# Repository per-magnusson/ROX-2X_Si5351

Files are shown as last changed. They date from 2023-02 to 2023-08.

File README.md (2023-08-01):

# ROX-2X_Si5351
Si5351 controller for a 2 m ARDF receiver, based on a Raspberry Pi Pico board

This code controls an Si5351 chip to work as the local oscillator in a direction
finding receiver for the 2 m band (144 MHz). The user interface is a 2x16 alphanumeric
LCD, a rotary encoder and four membrane buttons. It was designed to replace the 
VCO of the ROX-2X ARDF receiver, see http://open-circuit.co.uk/wp/receivers/rox-2x/

The PDF shows the connections around the Pi Pico as well as how the ROX-2X board was 
modified.

The Si5351 library from Adafruit was used, but significantly modified/extended to 
support the needs of this project.

Potentially interesting code includes:

* Extended Adafruit Si5351 library
* Interrupt driven rotary encoder
* An algorithm based on Farey fractions to approximate doubles with fractions

The normal view during an ARDF competition is that the top row of the display shows the battery status and 
a bar with the signal strength (RSSI). The length of this bar is dependent on the 
analog gain setting but could potentially be used to compare the signal along different 
bearings. Normally one would however just listen to the audio RSSI while sweeping the 
antenna in different directions.

The second row shows the tuned frequency and which of the preprogrammed frequencies is
currently selected. 

If neither the encoder, nor any of the four membrane keys have been used for the last 
10 seconds, they all become locked, except for key 1 which unlocks them. When they are 
unlocked, they have the following functions:

* 1, edit a more significant digit in the frequency.
* 2, edit a less significant digit in the frequency.
* 3, step to the next stored frequency.
* 4, hold for a second to enter the "menu". "M" is shown in the lower right corner during this waiting period.
* Encoder, increment/decrement the currently active digit of the frequency.

When in the "menu", the first view allows editing of the stored frequencies. Key 1 changes which 
digit is edited. Key 2 jumps to the next frequency (up to 9 stored frequencies are supported). 
Key 3 stores the frequencies up to and including the currently selected frequency. 
Key 4 aborts this step and goes to the next menu screen without modifying the stored frequencies.

The second menu screen just shows the battery voltage. Pressing 4 moves on to the next screen.

The third menu screen can activate a function to characterize the pass band response 
(including the image reponse) of the receiver. A USB cable where a serial terminal looks at the printed 
output from the reciever shall be used to collect the resulting frequency/amplitude value pairs
which can then be plotted in e.g. Excel. An internal signal generator is used to create the 
test RF signal. Ideally, no antenna should be connected during this test. The result depends on the
gain setting. Press 1 to run this test or 4 to skip it.

The fourth menu item sweeps the tuning across the band and reports the RSSI at many frequencies 
as printouts on the USB serial port. This test could be used to look for internal disturbances from
the receiver itself, particularly if no antenna is connected during the test. The result depends on the
gain setting. Press 1 to run this test or 4 to skip it.

After the fourth menu screen, we are back to the main view used during a competition. So, to quickly go through the menus
if one accidentally enters it, key 4 can be pressed a couple of times to get back to the standard view.

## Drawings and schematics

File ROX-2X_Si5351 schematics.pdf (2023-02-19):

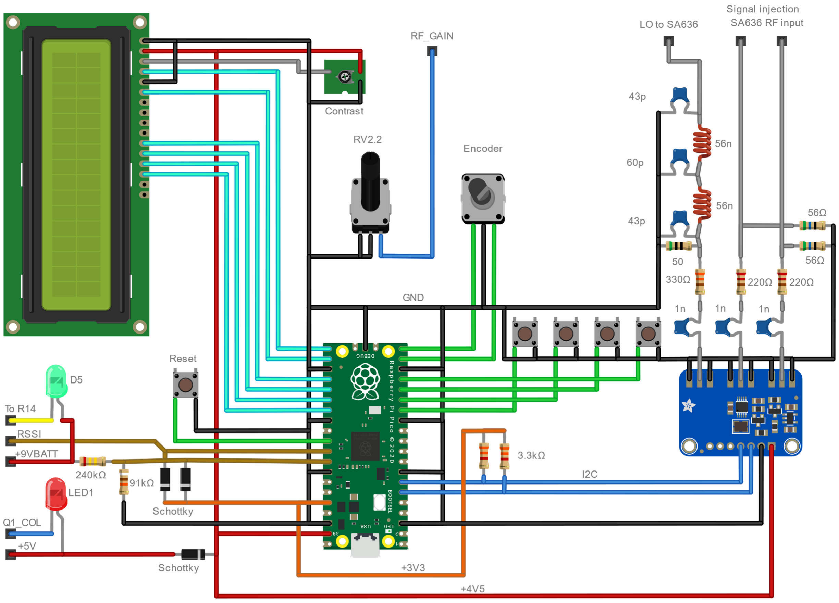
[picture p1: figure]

”Breadboard” connections for the Pi Pico, LCD, Si5351 board etc.

# Modified ROX-2X ARDF Receiver by G3ZOI

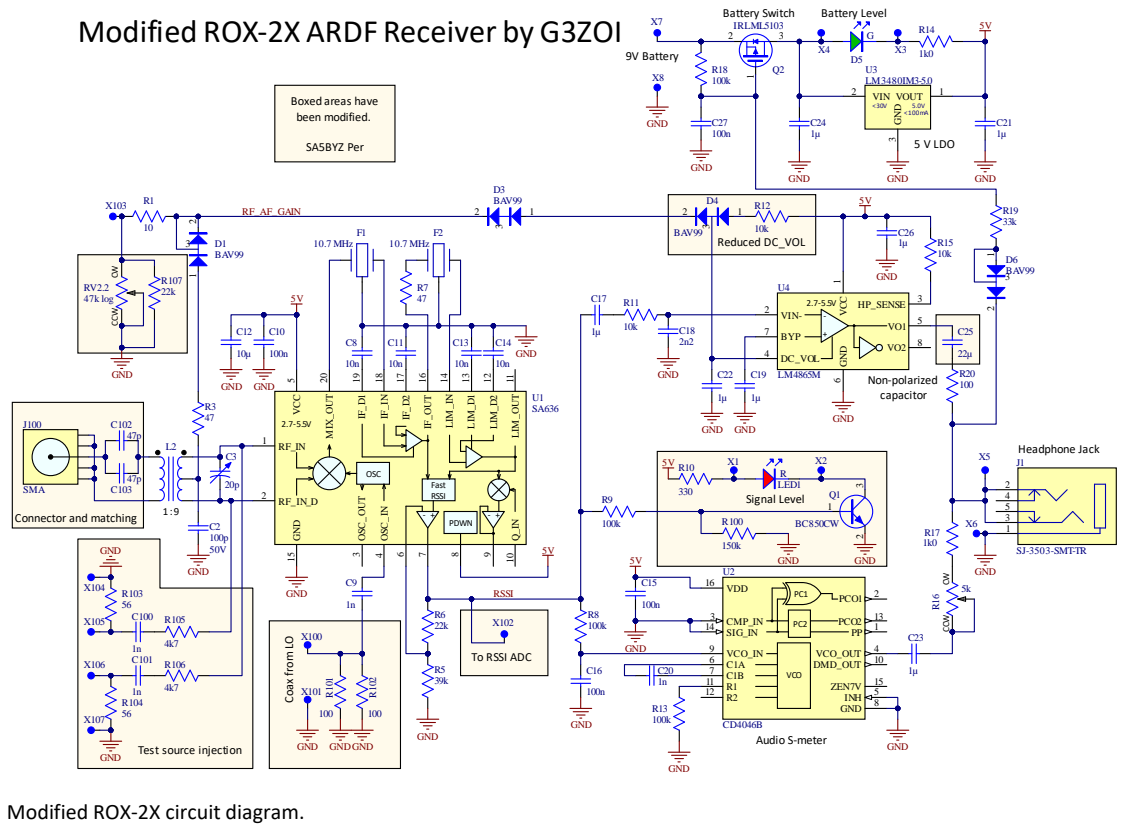
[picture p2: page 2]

Modified ROX-2X circuit diagram.

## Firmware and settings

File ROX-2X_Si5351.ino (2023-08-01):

// 2 m ARDF receiver local oscillator controller for ROX-2X
// based on an Raspberry Pi Pico board.
// Set the CPU clock frequency to 50 MHz in the Arduino IDE (Tools->CPU speed)
// to not have it near the LO and to save current.
// 2023-01-08 Per Magnusson
// This code is under the MIT license.

#include <LiquidCrystal.h>
#include <Bounce2.h>
#include <pico/stdlib.h>
#include "Encoder2.h"
#include "Adafruit_SI5351.h"
#include "Wire.h"
#include "rox2x.h"
#include "eeprom_2m.h"

static const int BUTTON1_Pin = 10;
static const int BUTTON2_Pin = 11;
static const int BUTTON3_Pin = 12;
static const int BUTTON4_Pin = 13;
static const int ENCODER_I_Pin = 14;
static const int ENCODER_Q_Pin = 15;
static const int LCD_RS_Pin = 16;
static const int LCD_EN_Pin = 17;
static const int LCD_D4_Pin = 18;
static const int LCD_D5_Pin = 19;
static const int LCD_D6_Pin = 20;
static const int LCD_D7_Pin = 21;
static const int RSSI_Pin = A0;
static const int DIV_9V_Pin = A1;

static const int LCD_WIDTH = 16;
static const int LCD_HEIGHT = 2;

static const int MENU_DLY_MS = 1000;  // Number of millisseconds to hold button to enter menu
static const int EDIT_DLY_MS = 10000; // Number of millisseconds until frequency edit is locked after last action

static const int MIN_FREQ_EDIT = 1000; // Hz, lowest increment when editing frequencies (the passband is about 50 kHz wide)
static const int MAX_FREQ_EDIT = 100000; // Hz, highest increment when editing frequencies
static const int MAX_TUNING_ERROR = 0; // Hz, maxmimum allowed deviation from ideal tuning frequency.
// There was speculation that higher values might give lower jitter since that allows a lower
// denominator, but actual measurements of spectra does not give a clear indication that that
// would be better.



// Voltage divider of 240k and 91k, 3.3 V ADC reference, 10 bits resolution and a fudge factor
static const float BATT_SCALE = 1.03*3.3*(240 + 91)/91/1024; 
static const float BATT_HIGH = 8.8; // Voltage regarded as full battery
static const float BATT_LOW = 6.5;  // Voltage regarded as empty battery
static const float BATT_LEVELS = 7; // Number of levels of battery indicator, one is below low and one is above high
static const float BATT_STEP = (BATT_HIGH - BATT_LOW)/(BATT_LEVELS - 2);


LiquidCrystal lcd(LCD_RS_Pin, LCD_EN_Pin, LCD_D4_Pin, LCD_D5_Pin, LCD_D6_Pin, LCD_D7_Pin);

Adafruit_SI5351 si5351 = Adafruit_SI5351();

Bounce button1 = Bounce();
Bounce button2 = Bounce();
Bounce button3 = Bounce();
Bounce button4 = Bounce();

uint32_t freq;  // Hz
uint32_t frequencies[10]; // Hz, read from EEPROM at power up, can be modified during use. 1-based, so only index 1-9 are used.
uint32_t max_frequency_idx = 1; // Highest used pre-programmed (EEPROM) frequency index
uint32_t current_freq_idx = 1;

static const int PLL_DELAY = 30; // Number of ms to wait after retuning a PLL

// Frequency sweeping parameters
static const uint SWEEP_FREQ_MIN = 144000000; // Hz
static const uint SWEEP_FREQ_MAX = 146000000;
static const uint SWEEP_FREQ_STEP_COARSE = 10000;
static const uint SWEEP_FREQ_STEP_FINE = 2000;
static const uint SWEEP_RSSI_AVG = 1000; // Number of RSSI measurements to average during sweeping


static const uint32_t IF_FREQ = 10700000; // Hz
int i2c_found;

void isr_a(void);
void isr_b(void);
void tune_pll(uint32_t pll_freq, uint32_t tolerance, si5351PLL_t pll);
void tune_freq(uint32_t freq);
void step_frequency();
float read_rssi(int n = 1);
int update_rssi();
float update_batt(uint32_t period_ms = 200);
void lcd_print_freq(uint32_t freq);
char *format_MHz(uint64_t freq);
void enable_test_source(uint32_t freq);
void disable_test_source();
void show_sweep_freq(uint32_t sweep_freq);


Encoder2 rot_enc(ENCODER_I_Pin, ENCODER_Q_Pin, isr_a, isr_b);

// Special LCD character codes
static const byte CHAR_BLOCK = 0; // Full block, used for RSSI
static const byte CHAR_RSSI = 1;  // Modifed block, used for top of RSSI
static const byte CHAR_BATT = 2;  // Modified battery level symbol
static const byte CHAR_RIGHT_ARROW = 3;  // Arrow pointing right
static const byte CHAR_ENTER = 4; // "Enter" sign

// Modifiable glyph for RSSI indication, starts out as a full block
byte glyph[8] = {
  0b11111,
  0b11111,
  0b11111,
  0b11111,
  0b11111,
  0b11111,
  0b11111,
  0b11111
};

// Glyphs for battery indication
byte batt_glyphs[7][8] = {
  {0b01110, 0b10001, 0b10001, 0b10001, 0b10001, 0b10001, 0b10001, 0b11111},
  {0b01110, 0b10001, 0b10001, 0b10001, 0b10001, 0b10001, 0b11111, 0b11111},
  {0b01110, 0b10001, 0b10001, 0b10001, 0b10001, 0b11111, 0b11111, 0b11111},
  {0b01110, 0b10001, 0b10001, 0b10001, 0b11111, 0b11111, 0b11111, 0b11111},
  {0b01110, 0b10001, 0b10001, 0b11111, 0b11111, 0b11111, 0b11111, 0b11111},
  {0b01110, 0b10001, 0b11111, 0b11111, 0b11111, 0b11111, 0b11111, 0b11111},
  {0b01110, 0b11111, 0b11111, 0b11111, 0b11111, 0b11111, 0b11111, 0b11111}
};

// Right arrow for use in menu
byte right_arrow_glyph[8] = {
  0b00000,
  0b00100,
  0b00010,
  0b11111,
  0b00010,
  0b00100,
  0b00000,
  0b00000
};

// "Enter" arrow for use in menu
byte enter_glyph[8] = {
  0b00000,
  0b00001,
  0b00001,
  0b01001,
  0b11111,
  0b01000,
  0b00000
};


void setup() {
  Serial.begin(115200);

  rp2040.enableDoubleResetBootloader();
  eeprom_init();
  max_frequency_idx = recall_frequencies(frequencies);
  current_freq_idx = 1;
  freq = frequencies[current_freq_idx];

  rot_enc.begin();
  button1.attach(BUTTON1_Pin, INPUT_PULLUP);
  button1.interval(10);
  button2.attach(BUTTON2_Pin, INPUT_PULLUP);
  button2.interval(10);
  button3.attach(BUTTON3_Pin, INPUT_PULLUP);
  button3.interval(10);
  button4.attach(BUTTON4_Pin, INPUT_PULLUP);
  button4.interval(10);

  si5351.begin();
  si5351.powerDownOutput(0, false);
  si5351.enableOutput(0, true);
  si5351.outputDrive(0, SI5351_DRIVE_2MA);
  si5351.outputDrive(1, SI5351_DRIVE_2MA);
  si5351.outputDrive(2, SI5351_DRIVE_2MA);
  si5351.invertOutput(2, true);
  si5351.enableOutput(1, false);
  si5351.enableOutput(2, false);
  si5351.setupMultisynthInt(0, SI5351_PLL_A, SI5351_MULTISYNTH_DIV_6);
  si5351.setupMultisynthInt(1, SI5351_PLL_B, SI5351_MULTISYNTH_DIV_6);
  si5351.setupMultisynthInt(2, SI5351_PLL_B, SI5351_MULTISYNTH_DIV_6);
  si5351.powerDownOutput(1, true);
  si5351.powerDownOutput(2, true);

  delay(PLL_DELAY);
  tune_freq(freq);
  si5351.resetPLL(SI5351_PLL_A);
  tune_pll(6*freq, 6*MAX_TUNING_ERROR, SI5351_PLL_B);
  si5351.resetPLL(SI5351_PLL_B);
  delay(PLL_DELAY);

  // set up the LCD's number of columns and rows:
  lcd.begin(LCD_WIDTH, LCD_HEIGHT);
  // Define custom characters
  lcd.createChar(CHAR_BLOCK, glyph);
  lcd.createChar(CHAR_BATT, batt_glyphs[6]);
  lcd.createChar(CHAR_RIGHT_ARROW, right_arrow_glyph);
  lcd.createChar(CHAR_ENTER, enter_glyph);

  // The following does not seem to work. Maybe better low-power functionality will be
  // added in the future. For now, the best thing to do seems to be to set the 
  // clock frequency to 50 MHz in the IDE.

  // Set clock frequency to 15.43 MHz to save power
  // set_sys_clock_khz(15429, false); 
  // Reduce core voltage
  // vreg_set_voltage(VREG_VOLTAGE_1_00); // 0.85V did not work, 0.95V seems pretty stable
}



// States of the "UI" state machine
typedef enum {
  S_FREQ_INIT, // Setup LO PLL
  S_FREQ_EDIT, // Rotating the dial adjusts the frequency
  S_BUTTON_LOCK, // Rotating the dial does not affect the frequency, button 1 needs to be pressed to unlock
  S_FREQ_MENU_DLY, // Waiting for button 4 to be pressed long enough to enter the menu
  S_MENU_FREQ1, // Init first menu (frequency edit)
  S_MENU_FREQ2, // Edit frequencies
  S_MENU_SHOW_SAVED, // Show "saved" message
  S_MENU_SHOW_CANCEL, // Show "cancelled" message
  S_MENU_BATT1, // Show battery voltage 1
  S_MENU_BATT2, // Show battery voltage 2
  S_MENU_SWEEP_RESP0, // Sweep passband reponse?
  S_MENU_SWEEP_RESP1, // Sweep passband!
  S_MENU_SWEEP_RESP2, // Sweep  
  S_MENU_SWEEP_RESP3, // Sweep  
  S_MENU_SWEEP_RESP4, // Sweep  
  S_MENU_SWEEP_RESP5, // Sweep  
  S_MENU_SWEEP_RESP6, // Sweep  
  S_MENU_SWEEP_RESP7, // Sweep  
  S_MENU_SWEEP_RESP_DONE1, // After sweep passband 
  S_MENU_SWEEP_RESP_DONE2, // After sweep  
  S_MENU_SWEEP_RESP_DONE3, // After sweep  
  S_MENU_SWEEP_BAND0, // Sweep entire band to e.g. listen for internal noise?
  S_MENU_SWEEP_BAND1, // Sweep
  S_MENU_SWEEP_BAND2, // Sweep
  S_MENU_SWEEP_BAND3, // Sweep
  S_MENU_SWEEP_BAND_DONE1, // After band sweep  
  S_MENU_SWEEP_BAND_DONE2 // After band sweep  
} uiState_t;


void loop()
{
  static uint64_t f_increment = 10000;  // Current rotary encoder frequency increment
  static int force_freq_update = 1;
  static uiState_t state = S_FREQ_INIT;
  static uint32_t last_button_time;
  static int edit_freq_idx;
  static uint32_t sweep_freq;
  int rot_temp;
  int cursor_has_moved = 0;  
  
  if(state < S_MENU_FREQ1) {
    // Only update RSSI etc if we are not in the menu
    cursor_has_moved = update_rssi();
    update_batt();
  }

  // GUI state machine
  if(state == S_FREQ_INIT) { // ##################################    S_FREQ_INIT
    si5351.powerDownOutput(0, false);
    si5351.outputDrive(0, SI5351_DRIVE_2MA);
    si5351.enableOutput(0, true);
    si5351.setupMultisynthInt(0, SI5351_PLL_A, SI5351_MULTISYNTH_DIV_6);
    tune_freq(freq);
    si5351.resetPLL(SI5351_PLL_A);
    delay(PLL_DELAY);
    state = S_FREQ_EDIT;

  } else if(state == S_FREQ_EDIT) { // ##################################    S_FREQ_EDIT
    button1.update();
    if(button1.fell()) {
      f_increment *= 10;
      last_button_time = millis();
      cursor_has_moved = 1;
    }
    button2.update();
    if(button2.fell()) {
      f_increment /= 10;
      last_button_time = millis();
      cursor_has_moved = 1;
    }
    if(f_increment > MAX_FREQ_EDIT) {
      f_increment = MIN_FREQ_EDIT;
    }
    if(f_increment < MIN_FREQ_EDIT) {
      f_increment = MAX_FREQ_EDIT;
    }
    button3.update();
    if(button3.fell()) {
      // Step to the next stored frequency.
      last_button_time = millis();
      step_frequency();
      force_freq_update = 1;  
    }
    button4.update();
    if(button4.fell()) {
      // Button 4 was pressed, we might be entering the menu
      last_button_time = millis();
      lcd.setCursor(14, 1);
      lcd.print(" M");
      state = S_FREQ_MENU_DLY;
    }
    rot_temp = rot_enc.read();
    if (rot_temp != 0 || force_freq_update) {
      force_freq_update = 0;
      last_button_time = millis();
      freq += rot_temp*f_increment;
      frequencies[current_freq_idx] = freq;
      rot_enc.write(0);
      tune_freq(freq);
      lcd.setCursor(0, 1);
      lcd_print_freq(freq);
      lcd.setCursor(15, 1);
      lcd.print(current_freq_idx); // Index of current frequency
      cursor_has_moved = 1;
      Serial.print(format_MHz(freq));
      Serial.print(" #");
      Serial.println(current_freq_idx);
    }
    if(cursor_has_moved) {
      // Enable and position the cursor to mark which digit of the frequency we can adjust.
      if(f_increment >= 100000) {
        lcd.setCursor(4, 1);
      } else if(f_increment >= 10000) {
        lcd.setCursor(5, 1);
      } else if(f_increment >= 1000) {
        lcd.setCursor(6, 1);
      } else {
        lcd.setCursor(8, 1);
      }
      lcd.cursor();
    }

    if(millis() > last_button_time + EDIT_DLY_MS) {
      // Button time out, lock the frequency
      state = S_BUTTON_LOCK;
      lcd.noCursor();
    }
 
  } else if(state == S_BUTTON_LOCK) { // ##################################    S_BUTTON_LOCK
    // The encoder is ignored in this state, need to press button 1 to unlock
    rot_enc.write(0); // Do not collect encoder clicks in this state
    button1.update();
    if(button1.fell()) {
      last_button_time = millis();
      lcd.clear();
      force_freq_update = 1;
      state = S_FREQ_EDIT;
    }

  } else if(state == S_FREQ_MENU_DLY) { // ##################################    S_FREQ_MENU_DLY
    // Button 4 has been pressed, we are waiting to see 
    // if it is held down long enough to enter the menu.
    button4.update();
    if(button4.read() == HIGH) {
      // The button was released early, go back to edit state
      last_button_time = millis();
      lcd.setCursor(14, 1);
      lcd.print("  "); // Overwrite menu countdown.
      state = S_FREQ_EDIT;
    } else {
      // Still holding the button
      if(millis() > last_button_time + MENU_DLY_MS) {
        // The button has been held long enough to enter the menu.
        f_increment = 100000;
        state = S_MENU_FREQ1;
      }
    }

  } else if(state == S_MENU_FREQ1) { // ##################################    S_MENU_FREQ1
    // Show the first menu page
    lcd.clear();
    lcd.setCursor(0, 1);
    // Soft buttons:
    // 1: Right (change digit)
    // 2: Next frequency
    // 3: Store this and previous frequencies (but not those with higher indices)
    // 4: Cancel the frequency edit
    lcd.print("1:- 2:+ 3:v  4:X"); 
    lcd.setCursor(2, 1);
    lcd.write(CHAR_RIGHT_ARROW); // Replace '-' with right arrow
    lcd.setCursor(10, 1);
    lcd.write(CHAR_ENTER); // Replace 'v' with enter arrow
    edit_freq_idx = 1;
    force_freq_update = 1;
    state = S_MENU_FREQ2;

  } else if(state == S_MENU_FREQ2) { // ##################################    S_MENU_FREQ2
    // Edit stored frequencies
    button1.update();
    if(button1.fell()) {
      // Change which digit we are editing
      f_increment /= 10;
      if(f_increment < MIN_FREQ_EDIT) {
        f_increment = MAX_FREQ_EDIT;
      }
      cursor_has_moved = 1;
    }
    button2.update();
    if(button2.fell()) {
      // Go to next frequency
      edit_freq_idx++;
      force_freq_update = 1;
      if(edit_freq_idx > 9) {
        edit_freq_idx = 1;
      }
      if(frequencies[edit_freq_idx] < MIN_TUNE_FREQ) {
        frequencies[edit_freq_idx] = DEFAULT_TUNE_FREQ;
      }
      if(frequencies[edit_freq_idx] > MAX_TUNE_FREQ) {
        frequencies[edit_freq_idx] = DEFAULT_TUNE_FREQ;
      }      
    }
    button3.update();
    if(button3.fell()) {
      // Store the frequencies up to and including the current one
      if(edit_freq_idx < 9) {
        frequencies[edit_freq_idx+1] = 0; // Make next frequency invalid to signal the number of valid frequencies
      }
      store_frequencies(frequencies);
      max_frequency_idx = edit_freq_idx;
      freq = frequencies[1];
      current_freq_idx = 1;
      state = S_MENU_SHOW_SAVED;
    }
    button4.update();
    if(button4.fell()) {
      // Cancel the storing of frequencies
      state = S_MENU_SHOW_CANCEL;
    }
    rot_temp = rot_enc.read();
    if (rot_temp != 0 || force_freq_update) {
      force_freq_update = 0;
      frequencies[edit_freq_idx] += rot_temp*f_increment;
      if(frequencies[edit_freq_idx] < MIN_TUNE_FREQ) {
        frequencies[edit_freq_idx] = MIN_TUNE_FREQ;
      }
      if(frequencies[edit_freq_idx] > MAX_TUNE_FREQ) {
        frequencies[edit_freq_idx] = MAX_TUNE_FREQ;
      }
      rot_enc.write(0);
      lcd.setCursor(0, 0);
      lcd_print_freq(frequencies[edit_freq_idx]);
      lcd.setCursor(15, 0);
      lcd.print(edit_freq_idx); // Index of current frequency
      cursor_has_moved = 1;
      Serial.print(format_MHz(frequencies[edit_freq_idx]));
      Serial.print(" #");
      Serial.println(edit_freq_idx);
    }
    if(cursor_has_moved) {
      // Enable and position the cursor to mark which digit of the frequency we can adjust.
      if(f_increment >= 100000) {
        lcd.setCursor(4, 0);
      } else if(f_increment >= 10000) {
        lcd.setCursor(5, 0);
      } else if(f_increment >= 1000) {
        lcd.setCursor(6, 0);
      } else {
        lcd.setCursor(8, 0);
      }
      lcd.cursor();
    }

  } else if(state == S_MENU_SHOW_SAVED) { // ##################################    S_MENU_SHOW_SAVED
    // Show saved message
    lcd.clear();
    lcd.noCursor();
    lcd.setCursor(0, 0);
    lcd.print(edit_freq_idx);
    lcd.print(" frequencies");
    lcd.setCursor(0, 1);
    lcd.print("saved");
    delay(3000);
    state = S_MENU_BATT1;

  } else if(state == S_MENU_SHOW_CANCEL) { // ##################################    S_MENU_SHOW_CANCEL
    // Show cancelled message
    lcd.clear();
    lcd.noCursor();
    lcd.print("Save cancelled");
    delay(500);
    state = S_MENU_BATT1;

  } else if(state == S_MENU_BATT1) { // ##################################    S_MENU_BATT1
    // Show battery voltage, step 1
    float batt;
    lcd.clear();
    lcd.setCursor(0, 0);
    lcd.print("Battery: ");
    batt = BATT_SCALE * analogRead(DIV_9V_Pin);
    lcd.print(batt);
    lcd.print(" V ");
    lcd.setCursor(0, 1);
    lcd.write(byte(CHAR_BATT));
    lcd.print("         4:Next");
    state = S_MENU_BATT2;

  } else if(state == S_MENU_BATT2) {
    // Show battery voltage, step 2
    float batt;
    batt = update_batt(200);
    if(batt > 0) {
      lcd.setCursor(9, 0);
      lcd.print(batt);
    }
    button4.update();
    if(button4.fell()) {
      // Next
      force_freq_update = 1;
      lcd.clear();
      lcd.setCursor(0, 0);
      lcd.print("Sweep response?");
      lcd.setCursor(0, 1);
      lcd.print("1:Sweep   4:Skip");
      enable_test_source(freq); // Turn on the test frequency to facilitate volume adjustment
      state = S_MENU_SWEEP_RESP0;
    }

  } else if(state == S_MENU_SWEEP_RESP0) { // ##################################    S_MENU_SWEEP_RESP0
    // Do a frequency sweep?
    button1.update();
    if(button1.fell()) {
      state = S_MENU_SWEEP_RESP1;
    }
    button4.update();
    if(button4.fell()) {
      disable_test_source();
      state = S_MENU_SWEEP_BAND0;
    }

  } else if(state == S_MENU_SWEEP_RESP1) { // ##################################    S_MENU_SWEEP_RESP1
    // Do a frequency sweep
    sweep_freq = freq - 2*IF_FREQ - 200000; // Check image rejection
    enable_test_source(sweep_freq);
    lcd.clear();
    lcd.setCursor(0, 0);
    lcd.print("Sweeping...");
    Serial.println("Sweeping passband shape");
    state = S_MENU_SWEEP_RESP2;

  } else if(state == S_MENU_SWEEP_RESP2) { // ##################################    S_MENU_SWEEP_RESP2
    // Doing a frequency sweep. Checking image rejection below image passband.
    tune_pll(6 * sweep_freq, 6*MAX_TUNING_ERROR, SI5351_PLL_B); // Tune, but do not reset the PLL
    show_sweep_freq(sweep_freq);
    Serial.print(sweep_freq);
    Serial.print(";");
    delay(PLL_DELAY);
    Serial.println(rssi_to_dbm(read_rssi(SWEEP_RSSI_AVG)));
    sweep_freq += SWEEP_FREQ_STEP_COARSE;
    if(sweep_freq > freq - 2*IF_FREQ - 40000) {
      sweep_freq -= SWEEP_FREQ_STEP_COARSE - SWEEP_FREQ_STEP_FINE;
      state = S_MENU_SWEEP_RESP3;
    }

  } else if(state == S_MENU_SWEEP_RESP3) { // ##################################    S_MENU_SWEEP_RESP3
    // Doing a frequency sweep. Checking image rejection in image passband.
    tune_pll(6 * sweep_freq, 6*MAX_TUNING_ERROR, SI5351_PLL_B); // Tune, but do not reset the PLL
    show_sweep_freq(sweep_freq);
    Serial.print(sweep_freq);
    Serial.print(";");
    delay(PLL_DELAY);
    Serial.println(rssi_to_dbm(read_rssi(SWEEP_RSSI_AVG)));
    sweep_freq += SWEEP_FREQ_STEP_FINE;
    if(sweep_freq > freq - 2*IF_FREQ + 40000) {
      sweep_freq -= SWEEP_FREQ_STEP_FINE - SWEEP_FREQ_STEP_COARSE;
      state = S_MENU_SWEEP_RESP4;
    }

} else if(state == S_MENU_SWEEP_RESP4) { // ##################################    S_MENU_SWEEP_RESP4
    // Doing a frequency sweep. Checking image rejection above image passband.
    tune_pll(6 * sweep_freq, 6*MAX_TUNING_ERROR, SI5351_PLL_B); // Tune, but do not reset the PLL
    show_sweep_freq(sweep_freq);
    Serial.print(sweep_freq);
    Serial.print(";");
    delay(PLL_DELAY);
    Serial.println(rssi_to_dbm(read_rssi(SWEEP_RSSI_AVG)));
    sweep_freq += SWEEP_FREQ_STEP_COARSE;
    if(sweep_freq > freq - 2*IF_FREQ + 200000) {
      sweep_freq = freq - 200000;
      Serial.println(); // Mark jump from image to real band with an empty line.
      state = S_MENU_SWEEP_RESP5;
    }

} else if(state == S_MENU_SWEEP_RESP5) { // ##################################    S_MENU_SWEEP_RESP5
    // Doing a frequency sweep. Checking rejection below passband.
    tune_pll(6 * sweep_freq, 6*MAX_TUNING_ERROR, SI5351_PLL_B); // Tune, but do not reset the PLL
    show_sweep_freq(sweep_freq);
    Serial.print(sweep_freq);
    Serial.print(";");
    delay(PLL_DELAY);
    Serial.println(rssi_to_dbm(read_rssi(SWEEP_RSSI_AVG)));
    sweep_freq += SWEEP_FREQ_STEP_COARSE;
    if(sweep_freq > freq - 40000) {
      sweep_freq -=  SWEEP_FREQ_STEP_COARSE - SWEEP_FREQ_STEP_FINE;
      state = S_MENU_SWEEP_RESP6;
    }

  } else if(state == S_MENU_SWEEP_RESP6) { // ##################################    S_MENU_SWEEP_RESP6
    // Doing a frequency sweep. Checking passband.
    tune_pll(6 * sweep_freq, 6*MAX_TUNING_ERROR, SI5351_PLL_B); // Tune, but do not reset the PLL
    show_sweep_freq(sweep_freq);
    Serial.print(sweep_freq);
    Serial.print(";");
    delay(PLL_DELAY);
    Serial.println(rssi_to_dbm(read_rssi(SWEEP_RSSI_AVG)));
    sweep_freq += SWEEP_FREQ_STEP_FINE;
    if(sweep_freq > freq + 40000) {
      sweep_freq -= SWEEP_FREQ_STEP_FINE - SWEEP_FREQ_STEP_COARSE;
      state = S_MENU_SWEEP_RESP7;
    }

} else if(state == S_MENU_SWEEP_RESP7) { // ##################################    S_MENU_SWEEP_RESP7
    // Doing a frequency sweep. Checking rejection above passband.
    tune_pll(6 * sweep_freq, 6*MAX_TUNING_ERROR, SI5351_PLL_B); // Tune, but do not reset the PLL
    show_sweep_freq(sweep_freq);
    Serial.print(sweep_freq);
    Serial.print(";");
    delay(PLL_DELAY);
    Serial.println(rssi_to_dbm(read_rssi(SWEEP_RSSI_AVG)));
    sweep_freq += SWEEP_FREQ_STEP_COARSE;
    if(sweep_freq > freq + 200000) {
      sweep_freq = freq;
      state = S_MENU_SWEEP_RESP_DONE1;
    }
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

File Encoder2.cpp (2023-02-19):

/* Interrupt driven rotary encoder routines.
   Target: Teensy 3.1, 4.0 etc
   
   Written by Per Magnusson, http://www.axotron.se
   v 1.0 2015-11-15
   v 1.1 2021-01-30 (object oriented rewrite)
   v 1.2 2023-01-01 (rewrite to avoid "static initialization order fiasco" 
                     and require a call to .begin())
   This program is public domain.
*/

#include "encoder2.h"


Encoder2::Encoder2(int pin_a_a, int pin_b_a, void isr_a(void), void isr_b(void)):
  pin_a(pin_a_a), pin_b(pin_b_a), _isr_a(isr_a), _isr_b(isr_b)
{
  rot_count = 0;
  rot_a_val = 1;
  rot_b_val = 1;
  rot_state = 0;
}

void Encoder2::begin(void)
{
  pinMode(pin_a, INPUT_PULLUP);
  pinMode(pin_b, INPUT_PULLUP);
  attachInterrupt(digitalPinToInterrupt(pin_a), _isr_a, CHANGE);
  attachInterrupt(digitalPinToInterrupt(pin_b), _isr_b, CHANGE);
}

int Encoder2::read(void)
{
  volatile int n;
   
  noInterrupts(); // Turn off interrupts
  n = rot_count;
  interrupts();
  return n; 
}


void Encoder2::write(int n)
{
  noInterrupts(); // Turn off interrupts
  rot_count = n;
  interrupts();
}


// Interrupt routines
void Encoder2::isr_rot_a_change()
{
  if(digitalRead(pin_a)) {
    rot_a_val = 1;
    update_rot();
  } else {
    rot_a_val = 0;
    update_rot();
  }
}


void Encoder2::isr_rot_b_change() 
{
  if(digitalRead(pin_b)) {
    rot_b_val = 1;
    update_rot();
  } else {
    rot_b_val = 0;
    update_rot();
  }
}


// Update rotary encoder accumulator. 
// This function is called by the interrupt routines.
void Encoder2::update_rot() 
{
  // Increment rot_count if going CW, decrement it if going CCW.
  // Do not increment anything if it was just a glitch.
  switch(rot_state) {
    case 0: // Idle state, look for direction
      if(!rot_b_val) {
        rot_state = 1;  // CW 1
      }
      if(!rot_a_val) {
        rot_state = 11; // CCW 1
      }
      break;
    case 1: // CW, wait for A low while B is low
      if(!rot_b_val) {
        if(!rot_a_val) {
          rot_count++;
          rot_state = 2; // CW 2
        }
      } else {
        if(rot_a_val) {
          // It was just a glitch on B, go back to start
          rot_state = 0;
        }
      }
      break;
    case 2: // CW, wait for B high
      if(rot_b_val) {
        rot_state = 3; // CW 3
      }
      break;
    case 3: // CW, wait for A high
      if(rot_a_val) {
        rot_state = 0; // back to idle (detent) state
      }
      break;
    case 11: // CCW, wait for B low while A is low
      if(!rot_a_val) {
        if(!rot_b_val) {
          rot_count--;
          rot_state = 12; // CCW 2
        }
      } else {
        if(rot_b_val) {
          // It was just a glitch on A, go back to start
          rot_state = 0;
        }
      }
      break;
    case 12: // CCW, wait for A high
      if(rot_a_val) {
        rot_state = 13; // CCW 3
      }
      break;
    case 13: // CCW, wait for B high
      if(rot_b_val) {
        rot_state = 0; // back to idle (detent) state
      }
      break;
  }
}

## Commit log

2023-02-19 Delete ROX-2X_Si5351 schematics.docx
    This was not intended to be added in the first place.
2023-02-19 Adding a Fritzing schematic
    Fritzing schematic of the "breadboard" part of the project.
    [ROX-2X modified.fzz]
2023-08-01 Update ROX-2X_Si5351.ino
    Fixed some issues with editing of the stored frequencies.
    [ROX-2X_Si5351.ino]
